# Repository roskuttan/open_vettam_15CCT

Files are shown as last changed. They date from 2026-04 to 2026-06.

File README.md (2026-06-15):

# open_vettam_15CCT

Tunable-white ceiling-light hardware project with a main control board and a
separate circular LED MCPCB.

## Current Hardware

### LED MCPCB

Verified from the current KiCad schematic and PCB:

- 130 mm circular board routed on `F.Cu`.
- 84 LEDs: 42 x `L128-5090HA35000K1` cool-white 5000 K and
  42 x `L128-3090HA35000K1` warm-white 3000 K.
- Six CW strings and six WW strings, each with a `6.8 ohm` resistor.
- LED power pads are `CW+`, `WW+`, and one shared `LED-`.
- The shared `LED-` pad connects to `GND0` used by both LED sheets.
- The three LED power wire pads are `3 x 6 mm`. The previous four separate
  power pads were `5 x 10 mm`.
- A `TMP112AIDRLR` temperature sensor is connected through `TEMP_3V3`,
  `TEMP_GND`, `TEMP_SCL`, and `TEMP_SDA` pads.

Sources:

- [`hardware/led-mcpcb/kicad/led_mcpcb.kicad_sch`](hardware/led-mcpcb/kicad/led_mcpcb.kicad_sch)
- [`hardware/led-mcpcb/kicad/led_mcpcb.kicad_pcb`](hardware/led-mcpcb/kicad/led_mcpcb.kicad_pcb)
- [`hardware/led-mcpcb/kicad/CW-5000.kicad_sch`](hardware/led-mcpcb/kicad/CW-5000.kicad_sch)
- [`hardware/led-mcpcb/kicad/WW-3000.kicad_sch`](hardware/led-mcpcb/kicad/WW-3000.kicad_sch)

### Main Board

Verified from the current KiCad schematic and PCB:

- 68.25 x 49 mm, two copper layers, fully routed.
- `24V` input with an `LMR51610YDBVR` buck regulator producing `3V3`.
- `ESP32-C6-MINI-1-N4` controller module.
- Two `TPS922053DRRR` LED drivers controlled by `PWM_CW` and `PWM_WW`.
- `LED_OUT` connector `J3` pinout:

| Pin | Current net |
|---:|---|
| 1 | `+24V` |
| 2 | `WW-` |
| 3 | `+24V` |
| 4 | `CW-` |

- `TEMP_IN` connector `J5` pinout:

| Pin | Current net |
|---:|---|
| 1 | `+3V3` |
| 2 | `GND` |
| 3 | `SCL` |
| 4 | `SDA` |

Sources:

- [`hardware/main-board/kicad/open_vettam_15CCT.kicad_sch`](hardware/main-board/kicad/open_vettam_15CCT.kicad_sch)
- [`hardware/main-board/kicad/open_vettam_15CCT.kicad_pcb`](hardware/main-board/kicad/open_vettam_15CCT.kicad_pcb)
- [`hardware/main-board/kicad/24v_Input.kicad_sch`](hardware/main-board/kicad/24v_Input.kicad_sch)
- [`hardware/main-board/kicad/24-5_buck.kicad_sch`](hardware/main-board/kicad/24-5_buck.kicad_sch)
- [`hardware/main-board/kicad/MCU.kicad_sch`](hardware/main-board/kicad/MCU.kicad_sch)
- [`hardware/main-board/kicad/cc_driver.kicad_sch`](hardware/main-board/kicad/cc_driver.kicad_sch)

## Interface Status

The current board files do not have matching LED power interfaces:

- The LED MCPCB uses `CW+`, `WW+`, and shared `LED-`.
- The main board still outputs `+24V`, `WW-`, `+24V`, and `CW-`.

The main-board LED-driver section must be revised before it can connect directly
to the current LED MCPCB interface.

## Repository Layout

```text
hardware/
  main-board/
    kicad/          Main-board KiCad source
    bom/            Main-board BOM export
    manufacturing/  Gerber ZIP, netlist, and stencil DXF files
  led-mcpcb/
    kicad/          LED-board KiCad source
    manufacturing/  LED-board stencil DXF
firmware/
  esp32-c6/         Firmware placeholder; no source code is present yet
docs/               Datasheets and manufacturing notes
cad/                Enclosure CAD
mechanical/         Mechanical models and assembly assets
```

Matter over Thread, CW/WW PWM, brightness control, and color-temperature control
are listed as planned firmware scope in
[`firmware/esp32-c6/README.md`](firmware/esp32-c6/README.md); they are not
implemented in this repository yet.

## License

- Hardware and CAD source: CERN-OHL-P-2.0
- Firmware and scripts: MIT
- Documentation and media: not licensed unless stated otherwise

See [`LICENSE`](LICENSE) and [`LICENSES/`](LICENSES/).

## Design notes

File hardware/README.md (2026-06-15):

# Hardware

Board-level source files and manufacturing assets.

- `main-board/`: ESP32-C6 control board
- `led-mcpcb/`: LED metal-core PCB
- `bom/`: shared or combined order BOMs

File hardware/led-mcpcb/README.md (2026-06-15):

# LED MCPCB

Metal-core LED board for the CW and WW LED strings.

- `kicad/`: KiCad schematic, PCB, and design rules
- `tools/`: placement helper files

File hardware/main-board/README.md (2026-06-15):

# Main Board

Main ESP32-C6 control board.

- `kicad/`: KiCad schematic and PCB source
- `bom/`: BOM exports
- `manufacturing/`: fabrication, stencil, and netlist outputs

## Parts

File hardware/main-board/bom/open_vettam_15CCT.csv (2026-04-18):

Reference | Value | Datasheet | Footprint | Qty | DNP
C1 | 0.1uF 50V | http://www.samsungsem.com/kr/support/product-search/mlcc/CL10B104KB8NNWC.jsp | CAPC1608X90N | 1
C2 | 1uF 50V | https://ds.yuden.co.jp/TYCOMPAS/or/detail?pn=UMK107AB7105KA-T&u=M | CAPC1608X95N | 1
C3 | 10uF 50V | https://datasheet.datasheetarchive.com/originals/distributors/DKDS-19/375194.pdf | CAPC3216X180N | 1
D1 | SMBJ26A | http://www.littelfuse.com/~/media/electronics/datasheets/tvs_diodes/littelfuse_tvs_diode_smbj_datasheet.pdf.pdf | DIOM5436X261N | 1
PAD1 | -24V_IN |  | TestPoint:TestPoint_Loop_D2.50mm_Drill1.0mm | 1
PAD2 | +24V_IN |  | TestPoint:TestPoint_THTPad_2.5x2.5mm_Drill1.2mm | 1
Q1 | SQJ457EP-T1_BE3 | https://www.vishay.com/doc?76628 | SQJ416EPT1_GE3 | 1
R1 | 100K 1% | https://www.yageo.com/upload/media/product/productsearch/datasheet/rchip/PYu-RC_Group_51_RoHS_L_12.pdf | RESC1608X55N | 1
Z1 | MMSZ15T1G | https://www.onsemi.com/pub/Collateral/MMSZ2V4T1-D.PDF | DIOM3716X135N | 1

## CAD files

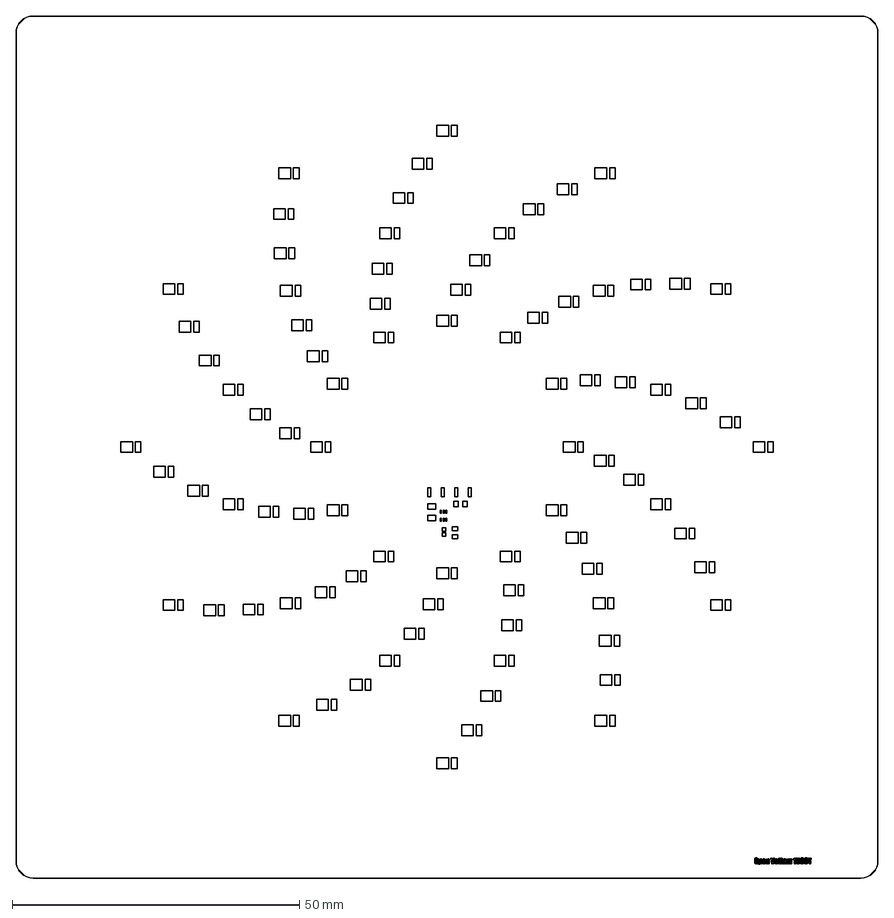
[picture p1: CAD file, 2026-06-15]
hardware/led-mcpcb/manufacturing/led_mcpcb-stencil.dxf
150.0 x 150.0 mm

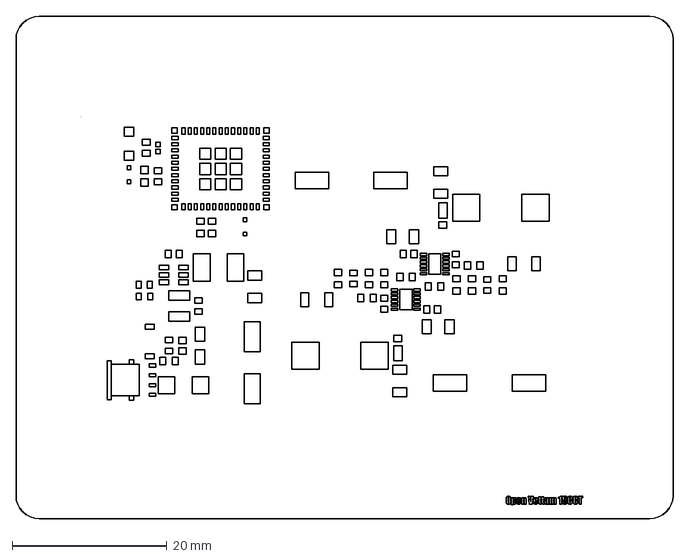
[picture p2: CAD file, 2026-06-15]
hardware/main-board/manufacturing/stencil/open_vettam_LED_stencil.dxf
85.0 x 65.0 mm

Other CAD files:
hardware/main-board/manufacturing/stencil/open_vettam_15CCT-F_Paste.dxf

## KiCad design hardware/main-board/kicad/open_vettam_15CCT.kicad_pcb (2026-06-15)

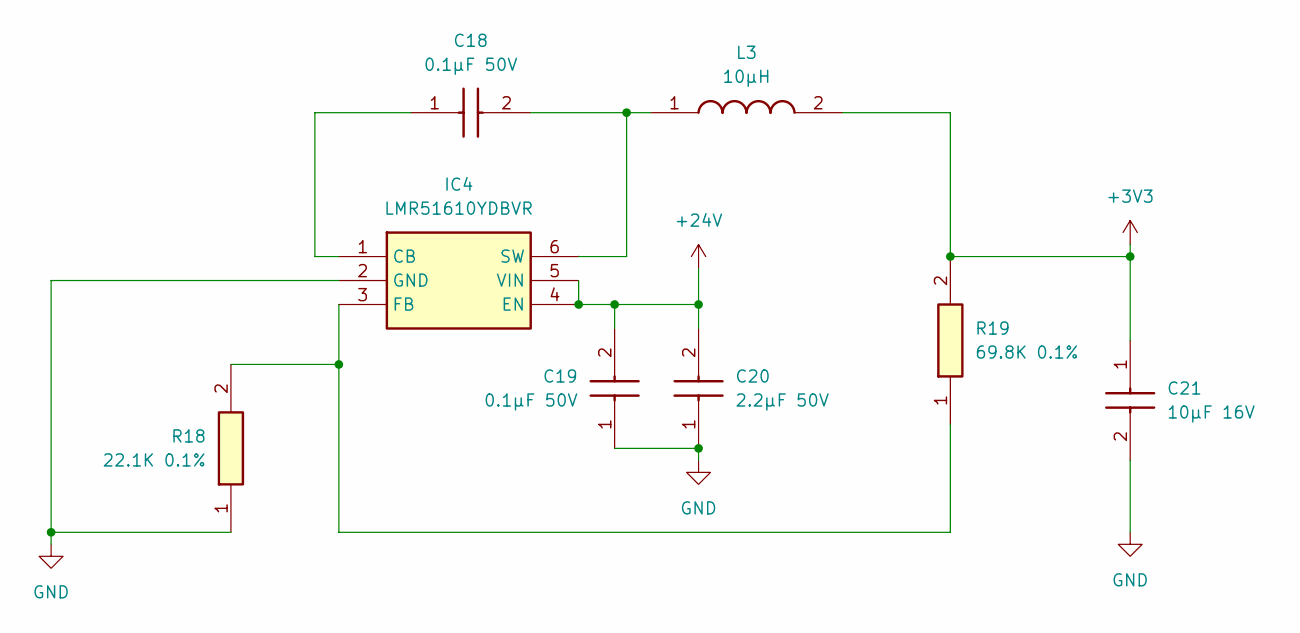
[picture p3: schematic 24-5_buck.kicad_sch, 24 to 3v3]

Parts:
C18, C19: 0.1µF 50V; CAPC1608X90N; Manufacturer_Part_Number CL10B104KB8NNNL; Mouser Part Number 187-CL10B104KB8NNNL
C20: 2.2µF 50V; CAPC3225X270N; Manufacturer_Part_Number CL32B225KBJNNNE; Mouser Part Number 187-CL32B225KBJNNNE
C21: 10µF 16V; CAPC3216X180N; Manufacturer_Part_Number C3216X7R1C106K160AC; Mouser Part Number 810-C3216X7R1C106K
IC4: LMR51610YDBVR; SOT95P280X145-6N; Manufacturer_Part_Number LMR51610YDBVR; Mouser Part Number 595-LMR51610YDBVR
L3: 10µH; SRP5030HMT2R2M; Manufacturer_Part_Number SRP5030HMT-100M; Mouser Part Number 652-SRP5030HMT-100M
R18: 22.1K 0.1%; ERA3AEB101V; Manufacturer_Part_Number ERA-3AEB2212V; Mouser Part Number 667-ERA-3AEB2212V
R19: 69.8K 0.1%; ERA3AEB101V; Manufacturer_Part_Number ERA-3AEB6982V; Mouser Part Number 667-ERA-3AEB6982V

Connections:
+3V3: C21.1, L3.2, R19.2; also elsewhere on the board
+24V: C19.2, C20.2, IC4.4 (EN), IC4.5 (VIN); also elsewhere on the board
GND: C19.1, C20.1, C21.2, IC4.2 (GND), R18.1; also elsewhere on the board
unnamed: C18.1, IC4.1 (CB)
unnamed: IC4.3 (FB), R18.2, R19.1
unnamed: C18.2, IC4.6 (SW), L3.1

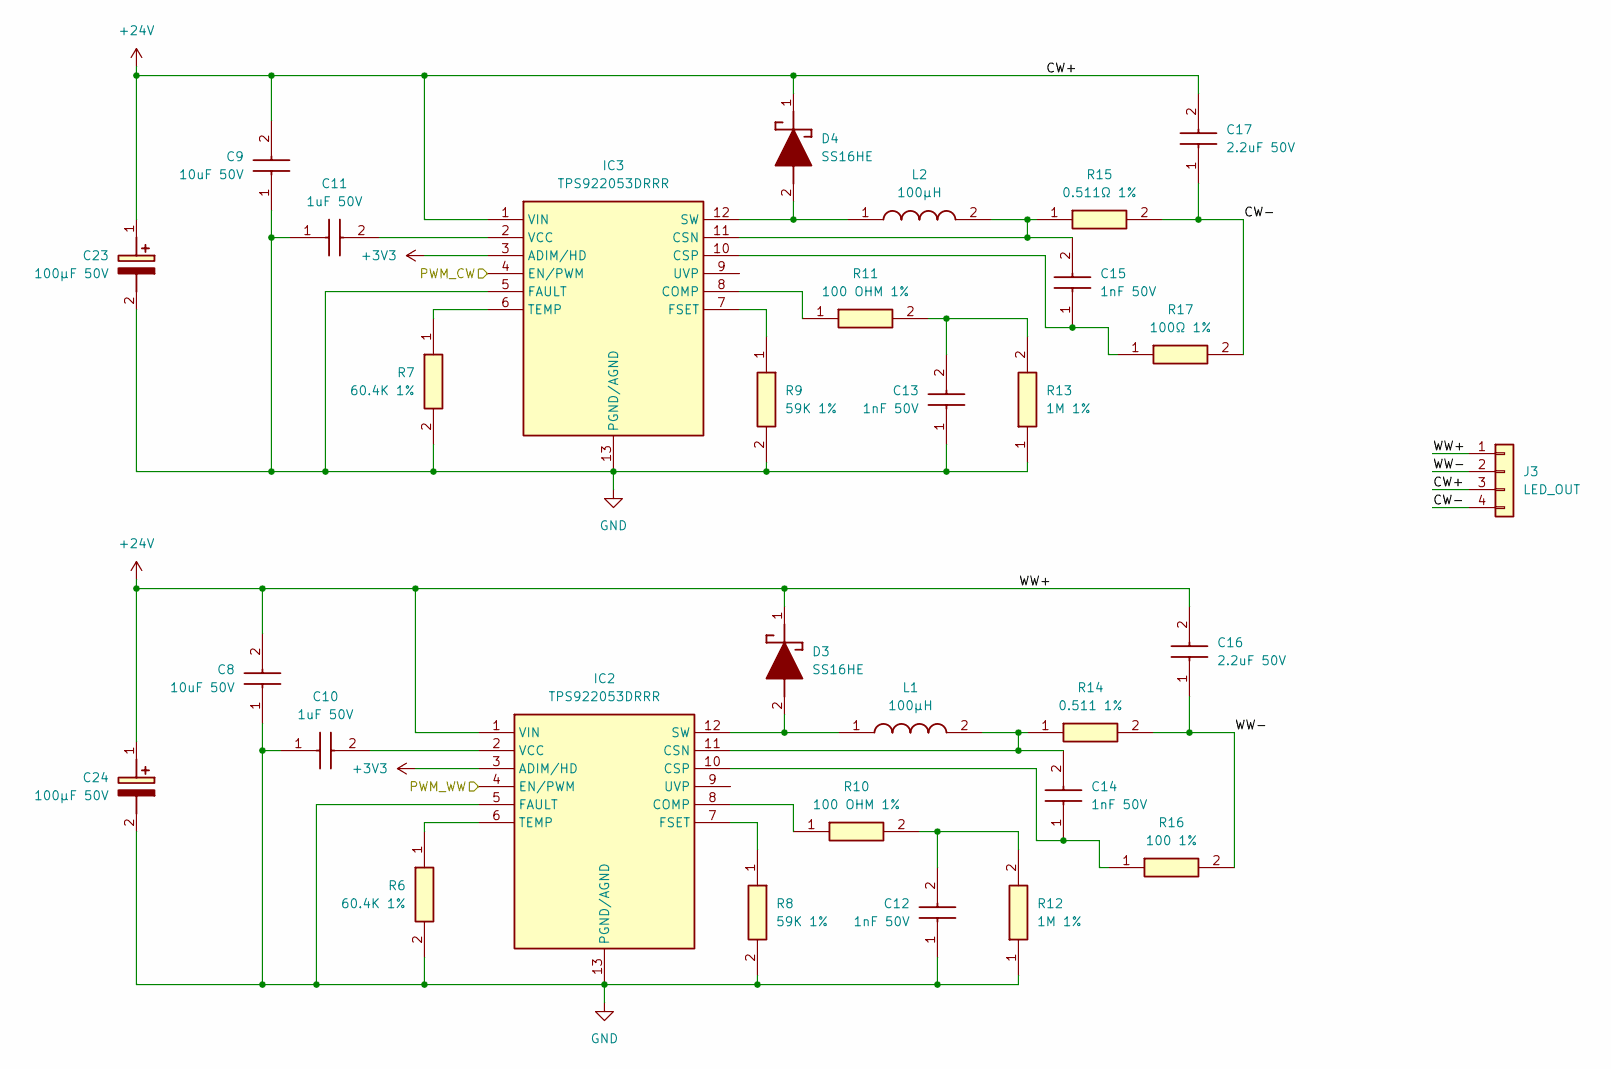
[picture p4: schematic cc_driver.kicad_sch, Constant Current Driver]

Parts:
C8, C9: 10uF 50V; CAPC3216X180N; Manufacturer_Part_Number CL31B106KBHNNNE; Mouser Part Number 187-CL31B106KBHNNNE
C10, C11: 1uF 50V; CAPC1608X95N; Manufacturer_Part_Number UMK107AB7105KA-T; Mouser Part Number 963-UMK107AB7105KA-T
C12, C13, C14, C15: 1nF 50V; CAPC1608X90N; Manufacturer_Part_Number CL10B102KB8NNNC; Mouser Part Number 187-CL10B102KB8NNNC
C16, C17: 2.2uF 50V; CAPC3216X180N; Manufacturer_Part_Number CL31B225KBHNNNE; Mouser Part Number 187-CL31B225KBHNNNE
C23, C24: 100µF 50V; CAPAE1030X1050N; Manufacturer_Part_Number 50THV100M10X10.5; Mouser Part Number 232-50THV100M10X10.5
D3, D4: SS16HE; Manufacturer_Part_Number SS16HE; Mouser Part Number 512-SS16HE
IC2, IC3: TPS922053DRRR; SON50P300X300X80-13N-D; Manufacturer_Part_Number TPS922053DRRR; Mouser Part Number 595-TPS922053DRRR
J3: LED_OUT; SolderWire-0.25sqmm_1x04_P4.5mm_D0.65mm_OD2mm
L1, L2: 100µH; AMDLA1004S101MT; Manufacturer_Part_Number AMDLA1004S-101MT; Mouser Part Number 815-AMDLA1004S-101MT
R6, R7: 60.4K 1%; RESC1608X55N; Manufacturer_Part_Number RC0603FR-0760K4L; Mouser Part Number 603-RC0603FR-0760K4L
R8, R9: 59K 1%; RESC1608X55N; Manufacturer_Part_Number RC0603FR-0759KL; Mouser Part Number 603-RC0603FR-0759KL
R10, R11: 100 OHM 1%; RESC1608X55N; Manufacturer_Part_Number RC0603FR-07100RL; Mouser Part Number 603-RC0603FR-07100RL
R12, R13: 1M 1%; RESC1608X55N; Manufacturer_Part_Number RC0603FR-071ML; Mouser Part Number 603-RC0603FR-071ML
R14: 0.511 1%; RESC3216X70N; Manufacturer_Part_Number SR732BTTDR511F; Mouser Part Number 660-SR732BTTER511F
R15: 0.511Ω 1%; RESC3216X70N; Manufacturer_Part_Number SR732BTTDR511F; Mouser Part Number 660-SR732BTTER511F
R16: 100 1%; RESC1608X55N; Manufacturer_Part_Number RC0603FR-07100RL; Mouser Part Number 603-RC0603FR-07100RL
R17: 100Ω 1%; RESC1608X55N; Manufacturer_Part_Number RC0603FR-07100RL; Mouser Part Number 603-RC0603FR-07100RL

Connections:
+3V3: IC2.3 (ADIM/HD), IC3.3 (ADIM/HD); also elsewhere on the board
+24V: C8.2, C9.2, C16.2, C17.2, C23.1 (+), C24.1 (+), D3.1 (K), D4.1 (K), IC2.1 (VIN), IC3.1 (VIN), J3.1, J3.3; also elsewhere on the board
/CC_Driver/CW-: C17.1, J3.4, R15.2, R17.2
/CC_Driver/PWM_CW: IC3.4 (EN/PWM); also elsewhere on the board
/CC_Driver/PWM_WW: IC2.4 (EN/PWM); also elsewhere on the board
/CC_Driver/WW-: C16.1, J3.2, R14.2, R16.2
GND: C8.1, C9.1, C10.1, C11.1, C12.1, C13.1, C23.2 (-), C24.2 (-), IC2.5 (FAULT), IC2.13 (PGND/AGND), IC3.5 (FAULT), IC3.13 (PGND/AGND), R6.2, R7.2, R8.2, R9.2, R12.1, R13.1; also elsewhere on the board
unnamed: C12.2, R10.2, R12.2
unnamed: C13.2, R11.2, R13.2
unnamed: D3.2 (A), IC2.12 (SW), L1.1
unnamed: D4.2 (A), IC3.12 (SW), L2.1
unnamed: IC2.8 (COMP), R10.1
unnamed: C14.2, IC2.11 (CSN), L1.2, R14.1
unnamed: C14.1, IC2.10 (CSP), R16.1
unnamed: IC2.7 (FSET), R8.1
unnamed: IC2.6 (TEMP), R6.1
unnamed: C10.2, IC2.2 (VCC)
unnamed: IC3.8 (COMP), R11.1
unnamed: C15.2, IC3.11 (CSN), L2.2, R15.1
unnamed: C15.1, IC3.10 (CSP), R17.1
unnamed: IC3.7 (FSET), R9.1
unnamed: IC3.6 (TEMP), R7.1
unnamed: C11.2, IC3.2 (VCC)

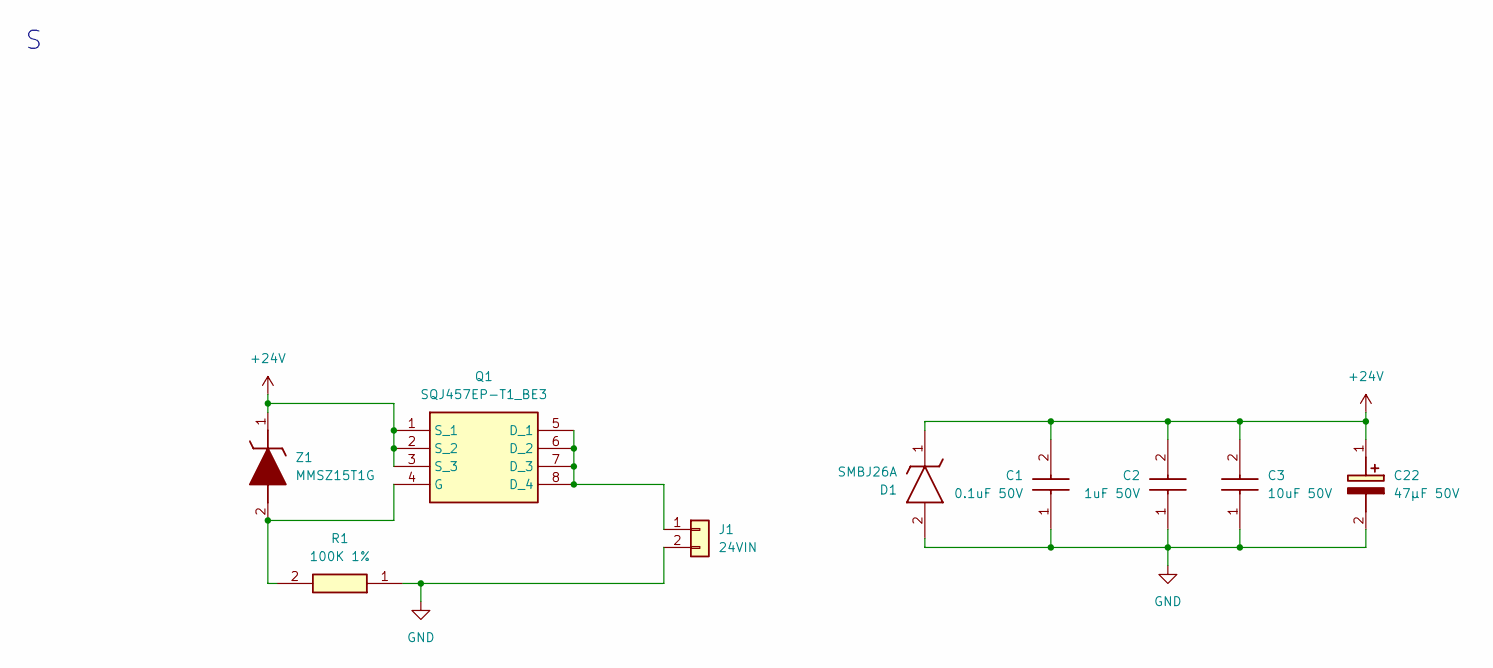
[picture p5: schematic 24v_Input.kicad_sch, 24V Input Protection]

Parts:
C1: 0.1uF 50V; CAPC1608X90N; Manufacturer_Part_Number CL10B104KB8NNWC; Mouser Part Number 187-CL10B104KB8NNWC
C2: 1uF 50V; CAPC1608X95N; Manufacturer_Part_Number UMK107AB7105KA-T; Mouser Part Number 963-UMK107AB7105KA-T
C3: 10uF 50V; CAPC3216X180N; Manufacturer_Part_Number CL31B106KBHNNNE; Mouser Part Number 187-CL31B106KBHNNNE
C22: 47µF 50V; CAPAE830X1050N; Manufacturer_Part_Number HHXC500ARA470MHA0G; Mouser Part Number 661-HHXC500A470MHA0G
D1: SMBJ26A; DIOM5436X261N; Manufacturer_Part_Number SMBJ26A; Mouser Part Number 576-SMBJ26A
J1: 24VIN; SolderWire-0.15sqmm_1x06_P4mm_D0.5mm_OD1.5mm
Q1: SQJ457EP-T1_BE3; SQJ416EPT1_GE3; Manufacturer_Part_Number SQJ457EP-T1_BE3; Mouser Part Number 78-SQJ457EP-T1_BE3
R1: 100K 1%; RESC1608X55N; Manufacturer_Part_Number RC0603FR-07100KL; Mouser Part Number 603-RC0603FR-07100KL
Z1: MMSZ15T1G; DIOM3716X135N; Manufacturer_Part_Number MMSZ15T1G; Mouser Part Number 863-MMSZ15T1G

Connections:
+24V: C1.2, C2.2, C3.2, C22.1 (+), D1.1 (K), Q1.1 (S_1), Q1.2 (S_2), Q1.3 (S_3), Z1.1 (K); also elsewhere on the board
GND: C1.1, C2.1, C3.1, C22.2 (-), D1.2 (A), J1.2, R1.1; also elsewhere on the board
unnamed: J1.1, Q1.5 (D_1), Q1.6 (D_2), Q1.7 (D_3), Q1.8 (D_4)
unnamed: Q1.4 (G), R1.2, Z1.2 (A)

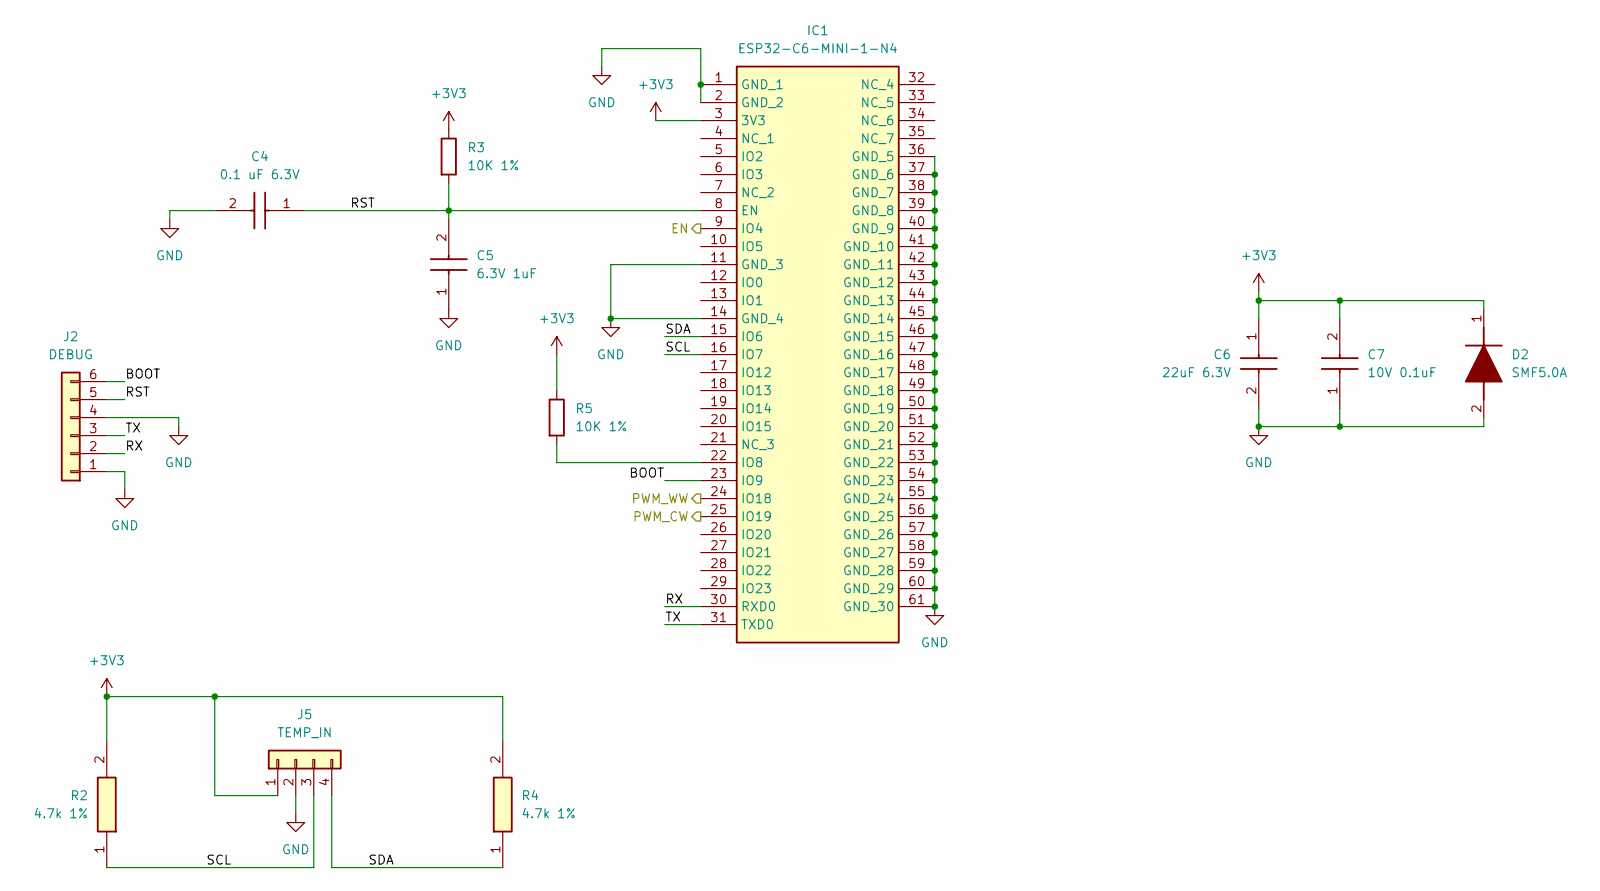
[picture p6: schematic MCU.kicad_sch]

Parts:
C4: 0.1 uF 6.3V; C0603; Manufacturer_Part_Number C0603C104K9PACTU; Mouser Part Number 80-C0603C104K9P
C5: 6.3V 1uF; CAPC1608X90N; Manufacturer_Part_Number CL10B105KQ8NNNC; Mouser Part Number 187-CL10B105KQ8NNNC
C6: 22uF 6.3V; CAPC1608X100N; Manufacturer_Part_Number CL10A226MQ8NRNE; Mouser Part Number 187-CL10A226MQ8NRNE
C7: 10V 0.1uF; C0402; Manufacturer_Part_Number C0402C104K8RACAUTO; Mouser Part Number 80-C0402C104K8RAUTO
D2: SMF5.0A; SODFL3618X110N; Manufacturer_Part_Number SMF5.0A; Mouser Part Number 576-SMF5.0A
IC1: ESP32-C6-MINI-1-N4; ESP32C6MINI1N4; Manufacturer_Part_Number ESP32-C6-MINI-1-N4; Mouser Part Number 356-ESP32C6MINI-1-N4
J2: DEBUG; SolderWire-0.15sqmm_1x06_P4mm_D0.5mm_OD1.5mm
J5: TEMP_IN; SolderWire-0.15sqmm_1x04_P4mm_D0.5mm_OD1.5mm
R2, R4: 4.7k 1%; RESC1608X55N; Manufacturer_Part_Number ERJ-3EKF4701V; Mouser Part Number 667-ERJ-3EKF4701V
R3, R5: 10K 1%; R_0603_1608Metric_Pad0.98x0.95mm_HandSolder; Manufacturer_Part_Number RC0603FR-0710KL; Mouser Part Number 603-RC0603FR-0710KL

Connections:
+3V3: C6.1, C7.2, D2.1 (K), IC1.3 (3V3), J5.1, R2.2, R3.1, R4.2, R5.1; also elsewhere on the board
/MCU/<NO NET>: IC1.23 (IO9), J2.6; also elsewhere on the board
/MCU/RST: C4.1, C5.2, IC1.8 (EN), J2.5, R3.2; also elsewhere on the board
/MCU/RX: IC1.30 (RXD0), J2.2; also elsewhere on the board
/MCU/SCL: IC1.16 (IO7), J5.3, R2.1; also elsewhere on the board
/MCU/SDA: IC1.15 (IO6), J5.4, R4.1; also elsewhere on the board
/MCU/TX: IC1.31 (TXD0), J2.3; also elsewhere on the board
GND: C4.2, C5.1, C6.2, C7.1, D2.2 (A), IC1.1 (GND_1), IC1.2 (GND_2), IC1.11 (GND_3), IC1.14 (GND_4), IC1.36 (GND_5), IC1.37 (GND_6), IC1.38 (GND_7), IC1.39 (GND_8), IC1.40 (GND_9), IC1.41 (GND_10), IC1.42 (GND_11), IC1.43 (GND_12), IC1.44 (GND_13), IC1.45 (GND_14), IC1.46 (GND_15), IC1.47 (GND_16), IC1.48 (GND_17), IC1.49 (GND_18), IC1.50 (GND_19), IC1.51 (GND_20), IC1.52 (GND_21), IC1.53 (GND_22), IC1.54 (GND_23), IC1.55 (GND_24), IC1.56 (GND_25), IC1.57 (GND_26), IC1.58 (GND_27), IC1.59 (GND_28), IC1.60 (GND_29), IC1.61 (GND_30), J2.1, J2.4, J5.2; also elsewhere on the board
unnamed 18: IC1.22 (IO8), R5.2; also elsewhere on the board

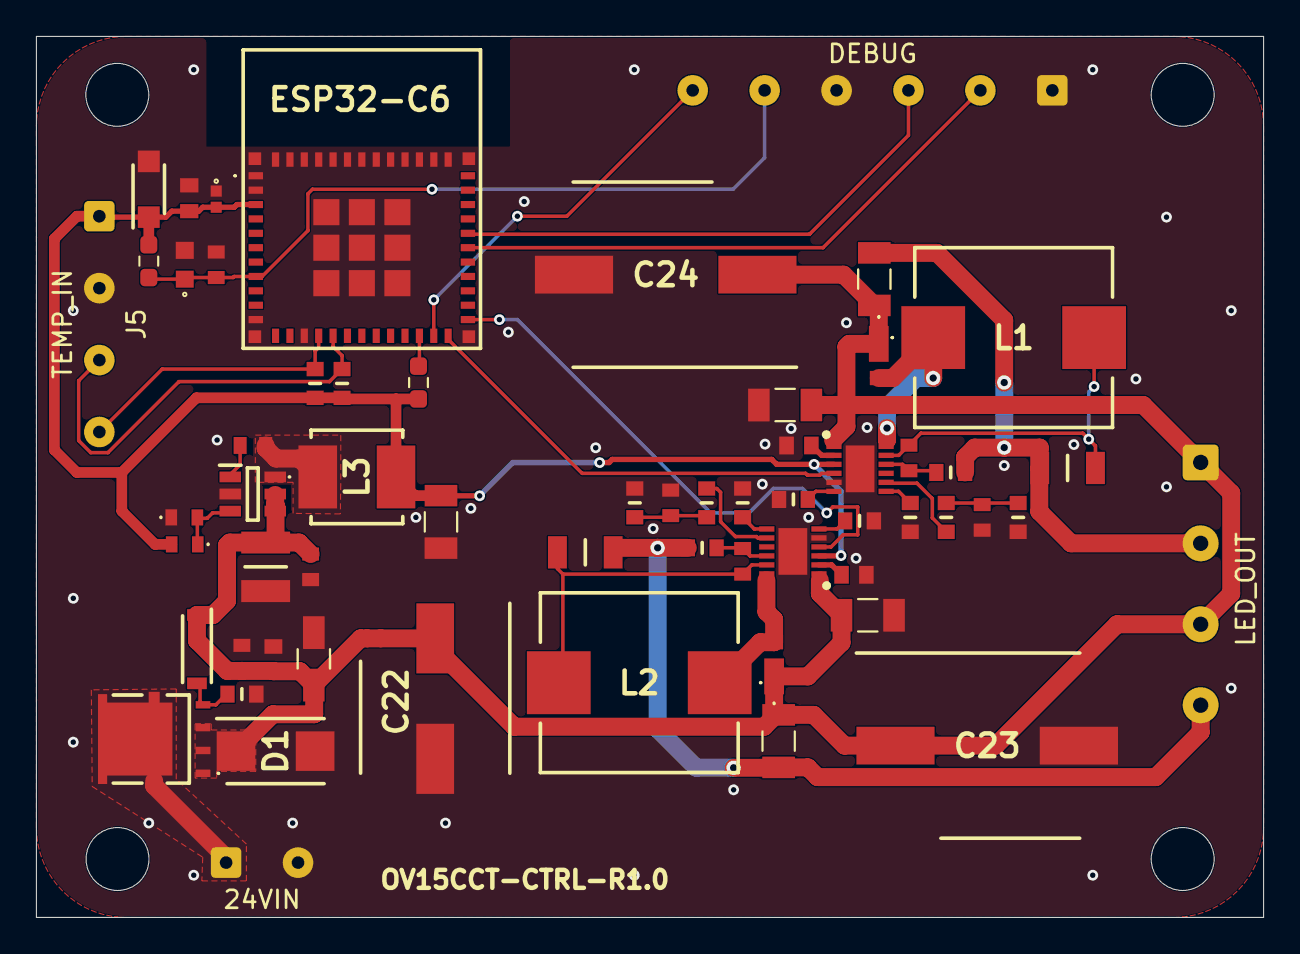
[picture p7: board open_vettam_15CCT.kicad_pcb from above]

Board: 2 copper layers, 68.2 x 49.0 mm, 60 parts (0 on the bottom side), 35 nets.

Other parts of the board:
ESP32-C6: ESP32-C6-MINI-1-N4; ESP32C6MINI1N4

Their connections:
+3V3: ESP32-C6.3 (3V3); also elsewhere on the board
/CC_Driver/PWM_CW: ESP32-C6.25 (IO19); also elsewhere on the board
/CC_Driver/PWM_WW: ESP32-C6.24 (IO18); also elsewhere on the board
/MCU/<NO NET>: ESP32-C6.23 (IO9); also elsewhere on the board
/MCU/RST: ESP32-C6.8 (EN); also elsewhere on the board
/MCU/RX: ESP32-C6.30 (RXD0); also elsewhere on the board
/MCU/SCL: ESP32-C6.16 (IO7); also elsewhere on the board
/MCU/SDA: ESP32-C6.15 (IO6); also elsewhere on the board
/MCU/TX: ESP32-C6.31 (TXD0); also elsewhere on the board
GND: ESP32-C6.1 (GND_1), ESP32-C6.2 (GND_2), ESP32-C6.11 (GND_3), ESP32-C6.14 (GND_4), ESP32-C6.36 (GND_5), ESP32-C6.37 (GND_6), ESP32-C6.38 (GND_7), ESP32-C6.39 (GND_8), ESP32-C6.40 (GND_9), ESP32-C6.41 (GND_10), ESP32-C6.42 (GND_11), ESP32-C6.43 (GND_12), ESP32-C6.44 (GND_13), ESP32-C6.45 (GND_14), ESP32-C6.46 (GND_15), ESP32-C6.47 (GND_16), ESP32-C6.48 (GND_17), ESP32-C6.49 (GND_18), ESP32-C6.50 (GND_19), ESP32-C6.51 (GND_20), ESP32-C6.52 (GND_21), ESP32-C6.53 (GND_22), ESP32-C6.54 (GND_23), ESP32-C6.55 (GND_24), ESP32-C6.56 (GND_25), ESP32-C6.57 (GND_26), ESP32-C6.58 (GND_27), ESP32-C6.59 (GND_28), ESP32-C6.60 (GND_29), ESP32-C6.61 (GND_30); also elsewhere on the board
unnamed 18: ESP32-C6.22 (IO8); also elsewhere on the board

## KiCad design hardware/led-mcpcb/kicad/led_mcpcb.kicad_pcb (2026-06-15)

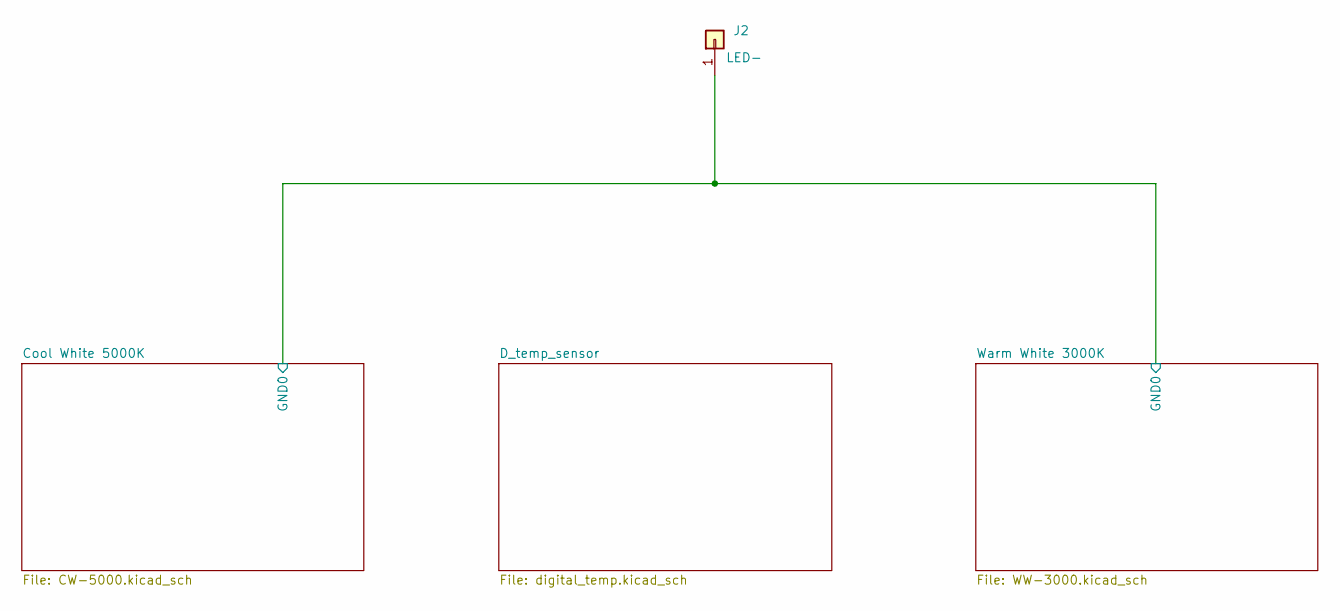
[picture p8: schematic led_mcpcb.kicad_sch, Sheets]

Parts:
J2: LED-; SolderWirePad_1x01_SMD_3x6mm

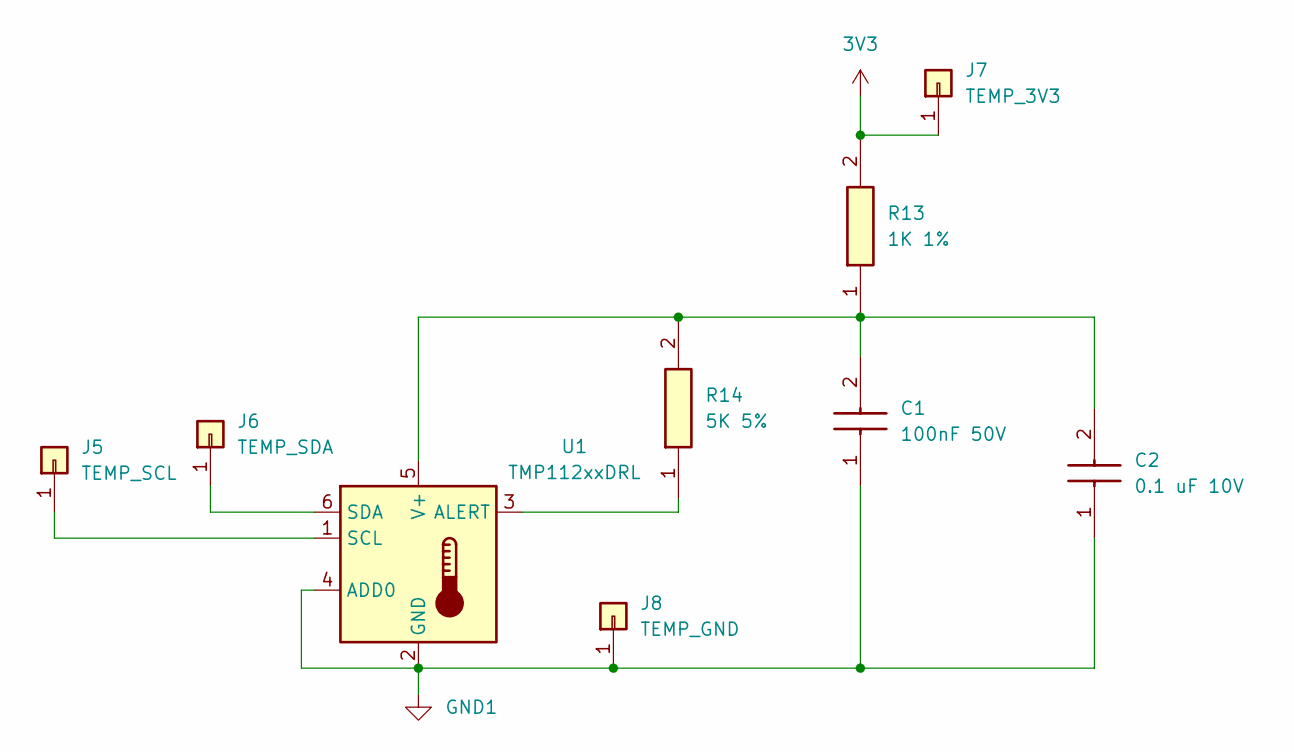
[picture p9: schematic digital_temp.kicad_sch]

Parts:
C1: 100nF 50V; CAPC1608X90N; Manufacturer_Part_Number CL10B104KB8NNNL; Mouser Part Number 187-CL10B104KB8NNNL
C2: 0.1 uF 10V; C0402; Manufacturer_Part_Number C0402C104K8RACAUTO; Mouser Part Number 80-C0402C104K8RAUTO
J5: TEMP_SCL; SolderWirePad_1x01_SMD_1x2mm
J6: TEMP_SDA; SolderWirePad_1x01_SMD_1x2mm
J7: TEMP_3V3; SolderWirePad_1x01_SMD_1x2mm
J8: TEMP_GND; SolderWirePad_1x01_SMD_1x2mm
R13: 1K 1%; RESC1608X55N; Manufacturer_Part_Number ERJ-3EKF1001V; Mouser Part Number 667-ERJ-3EKF1001V
R14: 5K 5%; RESC2012X50N; Manufacturer_Part_Number CRCW08055K00JNTA; Mouser Part Number 71-CRCW0805J-5K
U1: TMP112xxDRL; SOT-563; Manufacturer_Part_Number TMP112AIDRLR; Mouser Part Number 595-TMP112AIDRLR

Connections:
3V3: J7.1 (Pin_1_1), R13.2
GND1: C1.1, C2.1, J8.1 (Pin_1_1), U1.2 (GND), U1.4 (ADD0)
unnamed: J5.1 (Pin_1_1), U1.1 (SCL)
unnamed: J6.1 (Pin_1_1), U1.6 (SDA)
unnamed: R14.1, U1.3 (ALERT)
unnamed: C1.2, C2.2, R13.1, R14.2, U1.5 (V+)

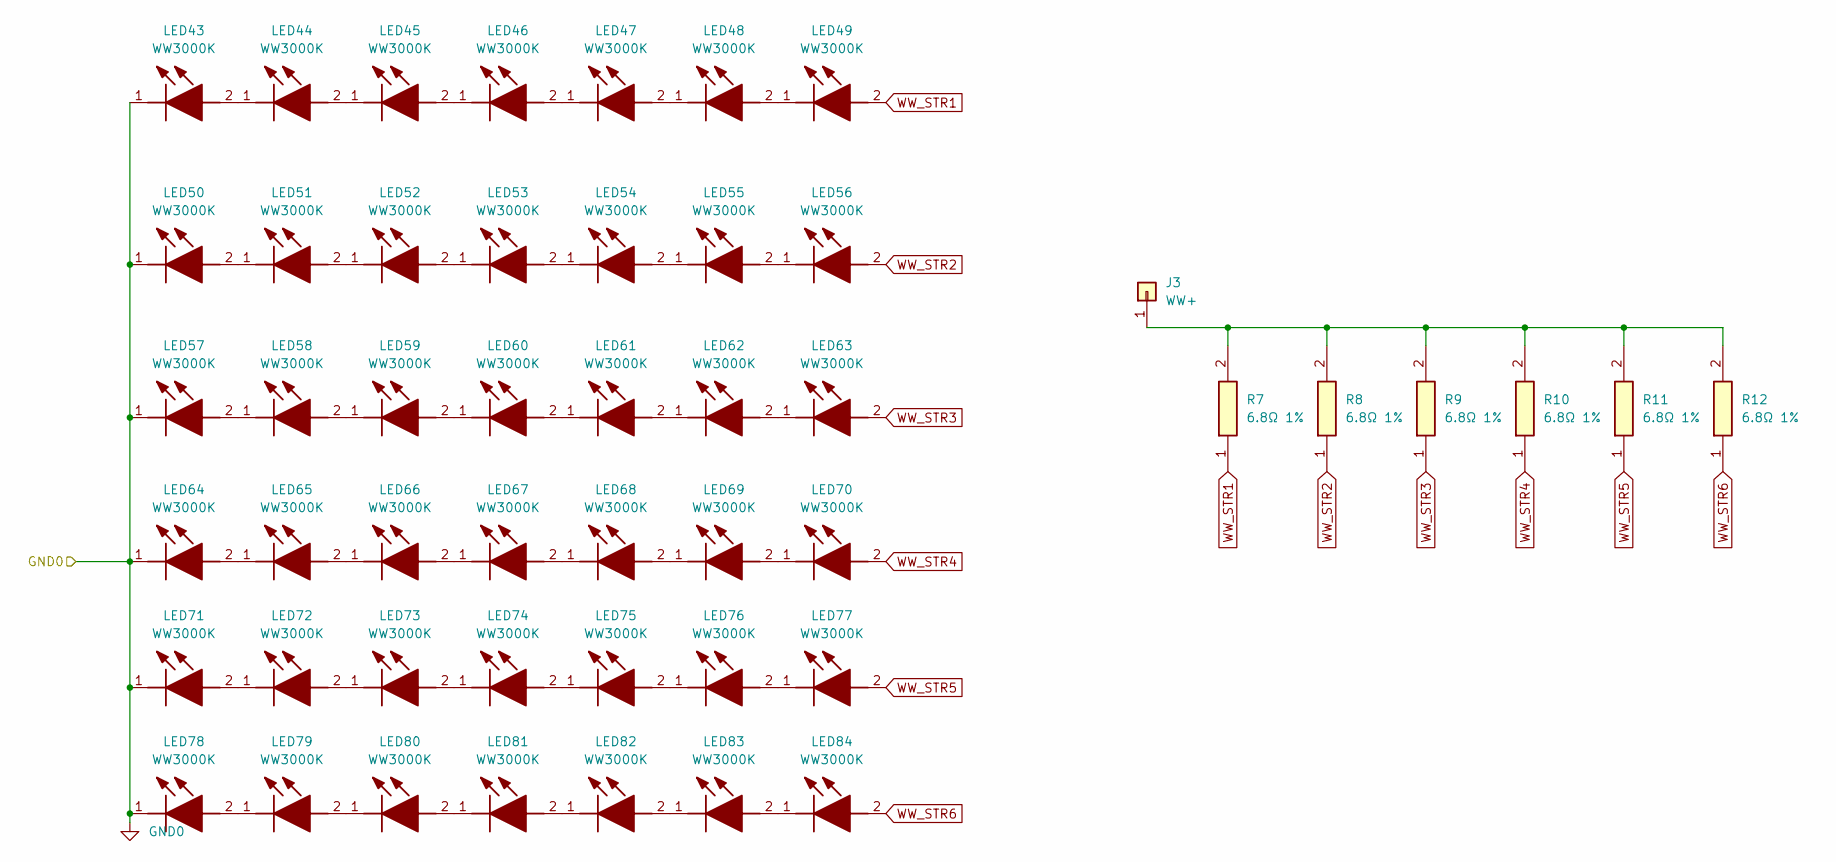
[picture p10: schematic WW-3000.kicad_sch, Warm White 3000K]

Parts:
J3: WW+; SolderWirePad_1x01_SMD_3x6mm
LED43, LED44, LED45, LED46, LED47, LED48, LED49, LED50, LED51, LED52, LED53, LED55, LED56, LED57, LED58, LED59, LED60, LED62, LED63, LED64, LED65, LED66, LED67, LED68, LED69, LED70, LED71, LED72, LED73, LED74, LED75, LED76, LED77, LED78, LED79, LED80, LED81, LED82, LED83, LED84: WW3000K; L1283090HA35000K1; Manufacturer_Part_Number L128-3090HA35000K1; Mouser Part Number 997-L1283090HA3500K1
LED54, LED61: WW3000K; L1285090HA35000K1; Manufacturer_Part_Number L128-3090HA35000K1; Mouser Part Number 997-L1283090HA3500K1
R7, R8, R9, R10, R11, R12: 6.8Ω 1%; RESC3116X65N; Manufacturer_Part_Number RC1206FR-076R8L; Mouser Part Number 603-RC1206FR-076R8L

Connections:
GND0: LED43.1 (K), LED50.1 (K), LED57.1 (K), LED64.1 (K), LED71.1 (K), LED78.1 (K); also elsewhere on the board
unnamed 10: J3.1, R7.2, R8.2, R9.2, R10.2, R11.2, R12.2; also elsewhere on the board
unnamed: LED43.2 (A), LED44.1 (K)
unnamed: LED44.2 (A), LED45.1 (K)
unnamed: LED45.2 (A), LED46.1 (K)
unnamed: LED46.2 (A), LED47.1 (K)
unnamed: LED47.2 (A), LED48.1 (K)
unnamed: LED48.2 (A), LED49.1 (K)
unnamed: LED50.2 (A), LED51.1 (K)
unnamed: LED51.2 (A), LED52.1 (K)
unnamed: LED52.2 (A), LED53.1 (K)
unnamed: LED53.2 (A), LED54.1 (K)
unnamed: LED54.2 (A), LED55.1 (K)
unnamed: LED55.2 (A), LED56.1 (K)
unnamed: LED57.2 (A), LED58.1 (K)
unnamed: LED58.2 (A), LED59.1 (K)
unnamed: LED59.2 (A), LED60.1 (K)
unnamed: LED60.2 (A), LED61.1 (K)
unnamed: LED61.2 (A), LED62.1 (K)
unnamed: LED62.2 (A), LED63.1 (K)
unnamed: LED64.2 (A), LED65.1 (K)
unnamed: LED65.2 (A), LED66.1 (K)
unnamed: LED66.2 (A), LED67.1 (K)
unnamed: LED67.2 (A), LED68.1 (K)
unnamed: LED68.2 (A), LED69.1 (K)
unnamed: LED69.2 (A), LED70.1 (K)
unnamed: LED71.2 (A), LED72.1 (K)
unnamed: LED72.2 (A), LED73.1 (K)
unnamed: LED73.2 (A), LED74.1 (K)
unnamed: LED74.2 (A), LED75.1 (K)
unnamed: LED75.2 (A), LED76.1 (K)
unnamed: LED76.2 (A), LED77.1 (K)
unnamed: LED78.2 (A), LED79.1 (K)
unnamed: LED79.2 (A), LED80.1 (K)
unnamed: LED80.2 (A), LED81.1 (K)
unnamed: LED81.2 (A), LED82.1 (K)
unnamed: LED82.2 (A), LED83.1 (K)
unnamed: LED83.2 (A), LED84.1 (K)
WW_STR1: LED49.2 (A), R7.1
WW_STR2: LED56.2 (A), R8.1
WW_STR3: LED63.2 (A), R9.1
WW_STR4: LED70.2 (A), R10.1
WW_STR5: LED77.2 (A), R11.1
WW_STR6: LED84.2 (A), R12.1

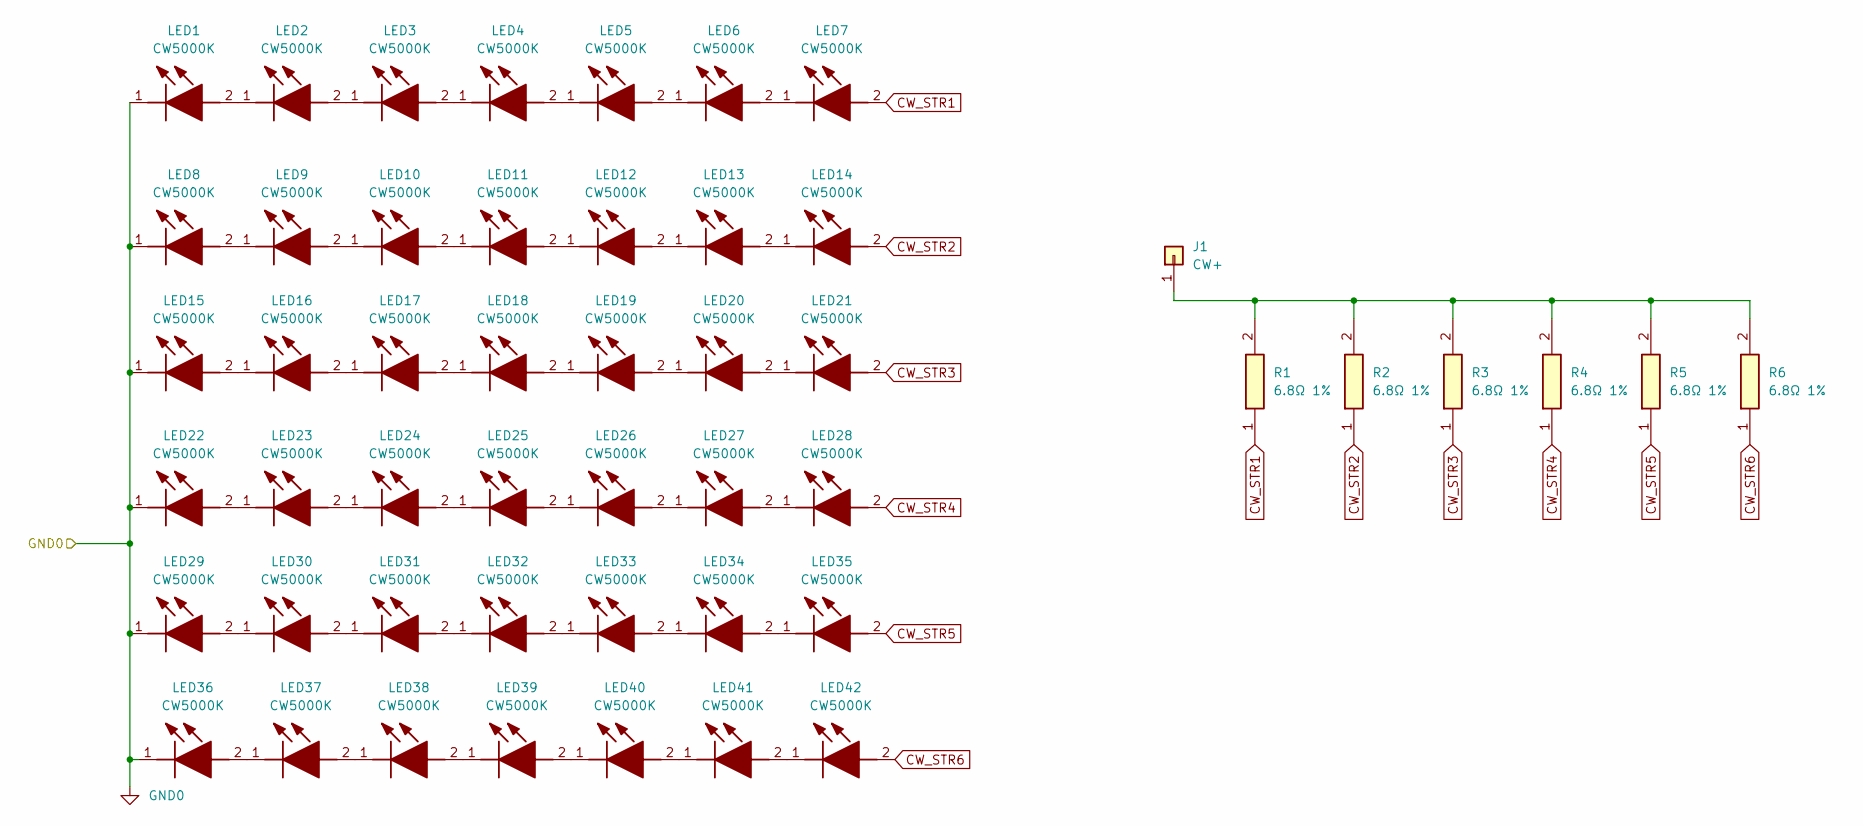
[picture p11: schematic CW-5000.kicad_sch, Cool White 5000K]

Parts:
J1: CW+; SolderWirePad_1x01_SMD_3x6mm
LED1, LED2, LED3, LED4, LED5, LED6, LED7, LED8, LED9, LED10, LED11, LED12, LED13, LED14, LED15, LED16, LED17, LED18, LED19, LED20, LED21, LED22, LED23, LED24, LED25, LED26, LED27, LED28, LED29, LED30, LED31, LED32, LED33, LED34, LED35, LED36, LED37, LED38, LED39, LED40, LED41, LED42: CW5000K; L1283090HA35000K1; Manufacturer_Part_Number L128-5090HA35000K1; Mouser Part Number 997-L1285090HA3500K1
R1, R2, R3, R4, R5, R6: 6.8Ω 1%; RESC3116X65N; Manufacturer_Part_Number RC1206FR-076R8L; Mouser Part Number 603-RC1206FR-076R8L

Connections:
CW_STR1: LED7.2 (A), R1.1
CW_STR2: LED14.2 (A), R2.1
CW_STR3: LED21.2 (A), R3.1
CW_STR4: LED28.2 (A), R4.1
CW_STR5: LED35.2 (A), R5.1
CW_STR6: LED42.2 (A), R6.1
GND0: LED1.1 (K), LED8.1 (K), LED15.1 (K), LED22.1 (K), LED29.1 (K), LED36.1 (K); also elsewhere on the board
unnamed 9: J1.1, R1.2, R2.2, R3.2, R4.2, R5.2, R6.2; also elsewhere on the board
unnamed: LED1.2 (A), LED2.1 (K)
unnamed: LED2.2 (A), LED3.1 (K)
unnamed: LED3.2 (A), LED4.1 (K)
unnamed: LED4.2 (A), LED5.1 (K)
unnamed: LED5.2 (A), LED6.1 (K)
unnamed: LED6.2 (A), LED7.1 (K)
unnamed: LED8.2 (A), LED9.1 (K)
unnamed: LED10.2 (A), LED11.1 (K)
unnamed: LED9.2 (A), LED10.1 (K)
unnamed: LED11.2 (A), LED12.1 (K)
unnamed: LED12.2 (A), LED13.1 (K)
unnamed: LED13.2 (A), LED14.1 (K)
unnamed: LED15.2 (A), LED16.1 (K)
unnamed: LED16.2 (A), LED17.1 (K)
unnamed: LED17.2 (A), LED18.1 (K)
unnamed: LED18.2 (A), LED19.1 (K)
unnamed: LED19.2 (A), LED20.1 (K)
unnamed: LED20.2 (A), LED21.1 (K)
unnamed: LED22.2 (A), LED23.1 (K)
unnamed: LED23.2 (A), LED24.1 (K)
unnamed: LED24.2 (A), LED25.1 (K)
unnamed: LED25.2 (A), LED26.1 (K)
unnamed: LED26.2 (A), LED27.1 (K)
unnamed: LED27.2 (A), LED28.1 (K)
unnamed: LED29.2 (A), LED30.1 (K)
unnamed: LED30.2 (A), LED31.1 (K)
unnamed: LED31.2 (A), LED32.1 (K)
unnamed: LED32.2 (A), LED33.1 (K)
unnamed: LED33.2 (A), LED34.1 (K)
unnamed: LED34.2 (A), LED35.1 (K)
unnamed: LED36.2 (A), LED37.1 (K)
unnamed: LED37.2 (A), LED38.1 (K)
unnamed: LED38.2 (A), LED39.1 (K)
unnamed: LED39.2 (A), LED40.1 (K)
unnamed: LED40.2 (A), LED41.1 (K)
unnamed: LED41.2 (A), LED42.1 (K)

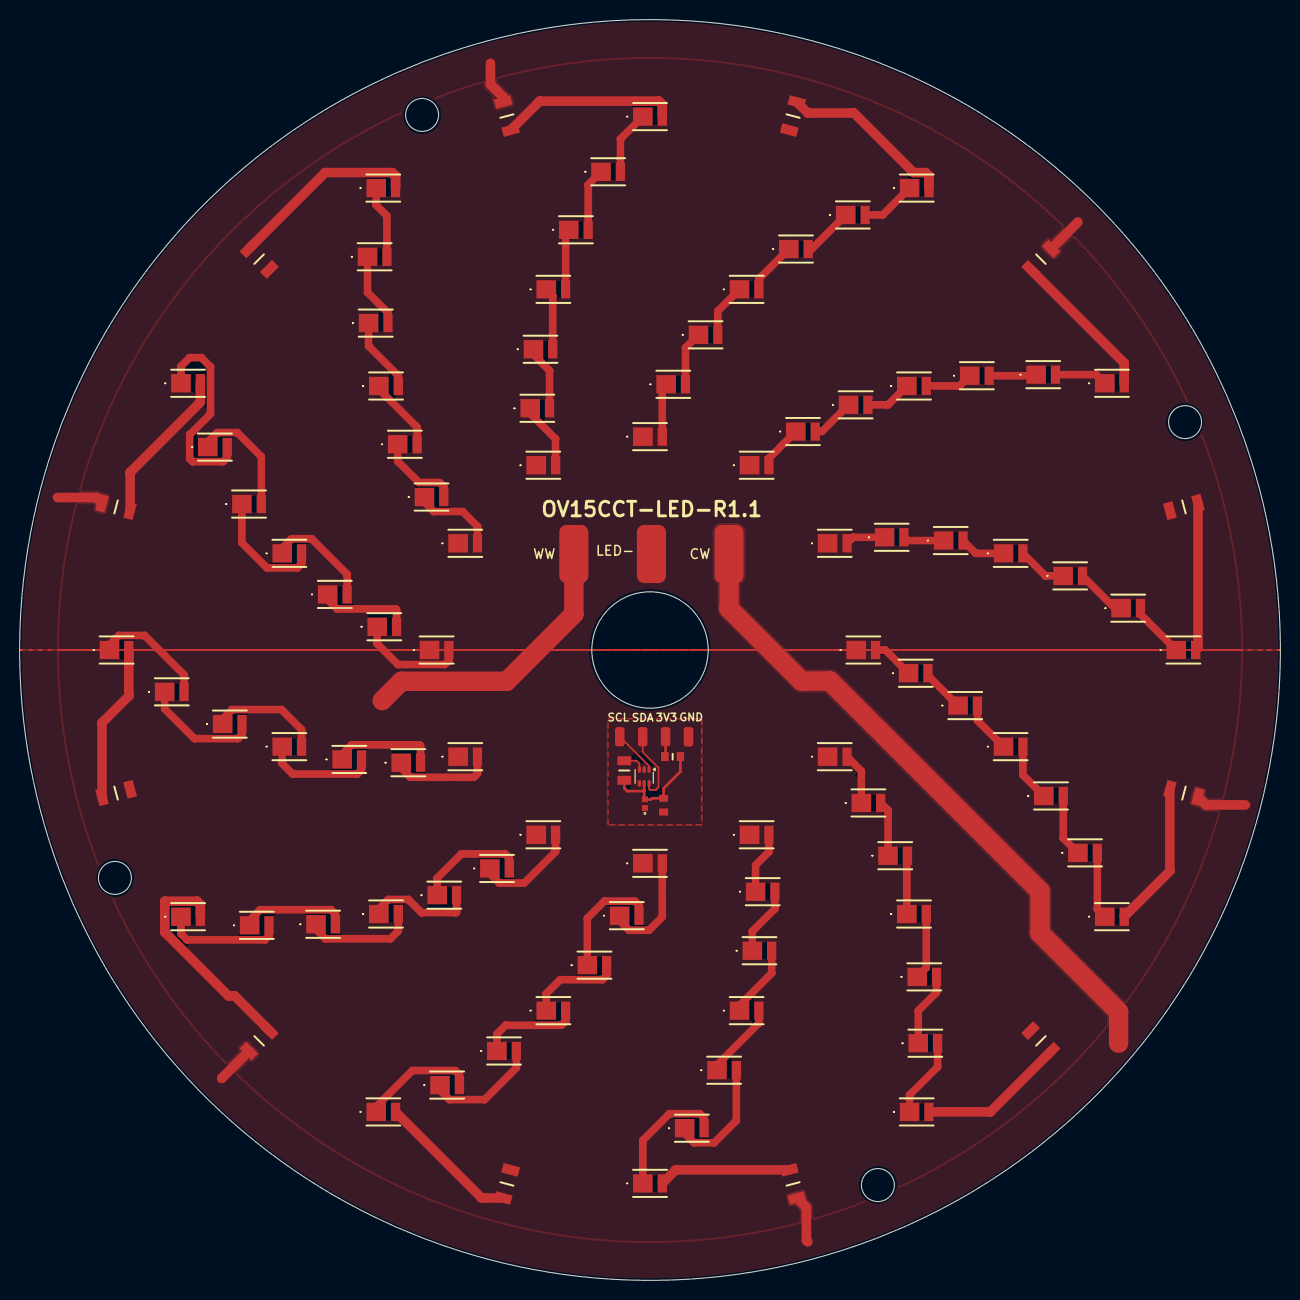
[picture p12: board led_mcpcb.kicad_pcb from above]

Board: 2 copper layers, 130.0 x 130.0 mm, 108 parts (0 on the bottom side), 93 nets.

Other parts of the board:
CW: CW+; SolderWirePad_1x01_SMD_3x6mm
LED-: LED-; SolderWirePad_1x01_SMD_3x6mm
WW: WW+; SolderWirePad_1x01_SMD_3x6mm

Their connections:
GND0: LED-.1 (Pin_1_1); also elsewhere on the board
unnamed 9: CW.1 (Pin_1_1); also elsewhere on the board
unnamed 10: WW.1 (Pin_1_1); also elsewhere on the board

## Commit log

2026-05-05 Finalize KiCad PCB sources for 5-piece test build
    Commit the completed Open Vettam 15CCT KiCad source design files prepared for the initial five-piece production test run.
    Included files are limited to the schematic hierarchy, PCB layouts, KiCad project files, and the LED MCPCB design-rules file. Generated BOM exports, fabrication output archives, freerouting/temp file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
    Updated main controller board sources:
    - open_vettam_15CCT.kicad_sch
    - open_vettam_15CCT.kicad_pcb
    - open_vettam_15CCT.kicad_pro
    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
    [24-5_buck.kicad_sch, 24v_Input.kicad_sch, CW-5000.kicad_sch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]
2026-06-15 Update LED MCPCB pads and shared LED return
    Reduce LED pin pad sizes for easier soldering and remove unnecessary pad area.
    Replace separate WW- and CW- connections with one shared LED- common connection for the planned common-connection driver IC.
    Organize the updated hardware source and manufacturing files under hardware/.
    [24-5_buck.kicad_sch, 24v_Input.kicad_sch, CW-5000.kicad_sch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]
